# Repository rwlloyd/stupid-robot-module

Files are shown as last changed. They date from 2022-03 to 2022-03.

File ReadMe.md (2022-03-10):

# Stupid Robot Module

An Example of building firmware for a multi-motor, serial controlled module for robotics applications.

module consists of a hoverboard wheel driven by a JY-01 500W brushless motor driver with hall sensor feedback. Drive Direction is controlled by a brushed DC motor and incremental encoder configured as a servo. Homing is achieved using a digital hall sensor and a magnet attached to one of the servo gears. The servo motor is driven by a L298D H-bridge. IO signals to the motors and sensors are provided by an Arduino Nano. Control signals are sent to the Arduino via Serial connection from a companion computer.

## Repository Structure

- ./Firmware/stupid-robot-module
    - main folder for arduino firmware. configuration for the functions already implemented can be done via config.h. 
    - modules
        - bigServo - l298d motor driver and incremental encoder. runs a position controll pid loop. homing doesn't work well, but after that it's fine.
        - comms - serial communication using a string of bytes. in this instance;
        
                [error, desiredAngle, wheelSetpoint, wheelDirection, wheelMode]

        - safety - a facility to check stops and do error checking
        - ucontrol - facility to setup the microcontroller timer. Currently stops the PWM signals being in the audible range.
        - wheel - controls the wheel via a JY-01 brushless motor driver with feedback. Position control and velocity control modes are implemented.

- ./Hardware
    - STLs and other drawings of the prototype. Have a look, but you are encouraged to roll your own.

- ./Kicad
    - The beginnings of a custom controller PCB

- ./Processing
    - Rudimentary user interface that connects from the host computer and controls the module via serial communication

If you want more information, raise an issue on the github repository :)

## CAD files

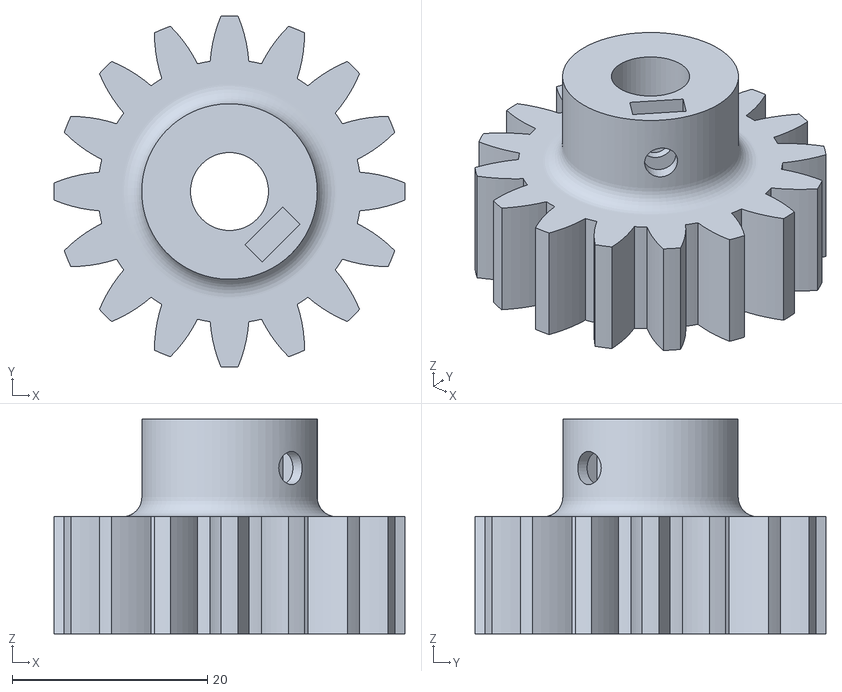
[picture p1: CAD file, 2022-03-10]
Hardware/Spur Gear1-Prototype.stl
36.0 x 36.0 x 22.0

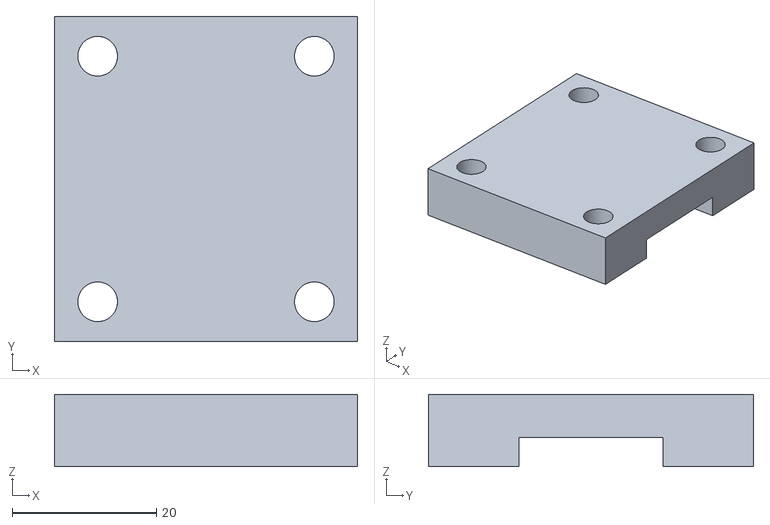
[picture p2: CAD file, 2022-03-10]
Hardware/WheelSprocketClamp.stl
42.0 x 45.0 x 10.0

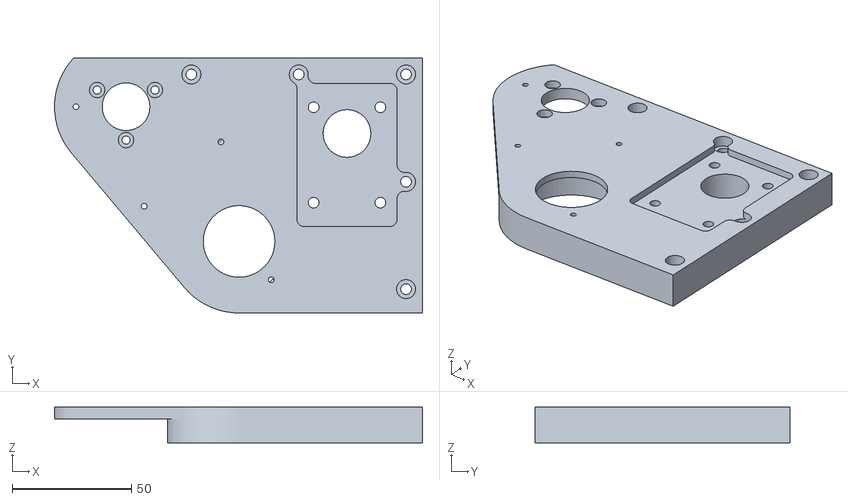
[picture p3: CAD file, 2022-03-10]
Hardware/SteeringMotorBracket-print.stl
154.3 x 106.9 x 15.0

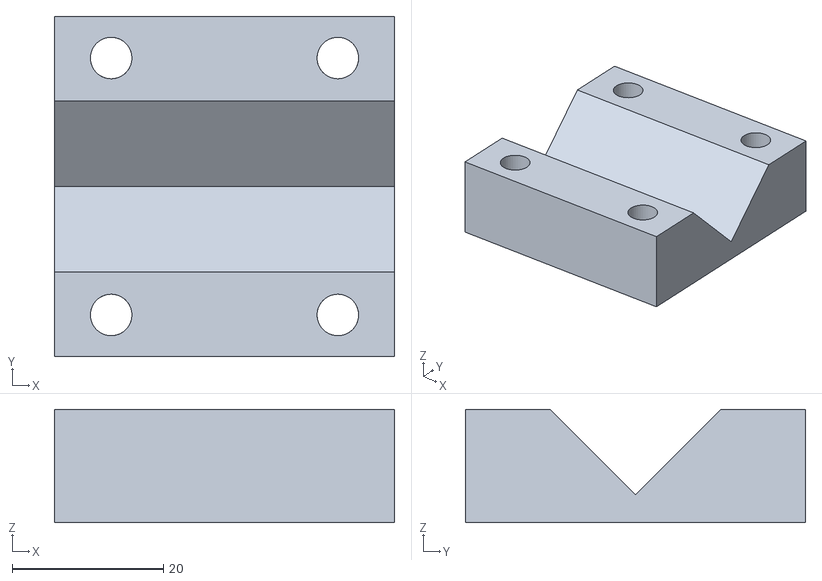
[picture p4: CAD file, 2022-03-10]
Hardware/DriveWheelVBlock.stl
45.0 x 45.0 x 15.0

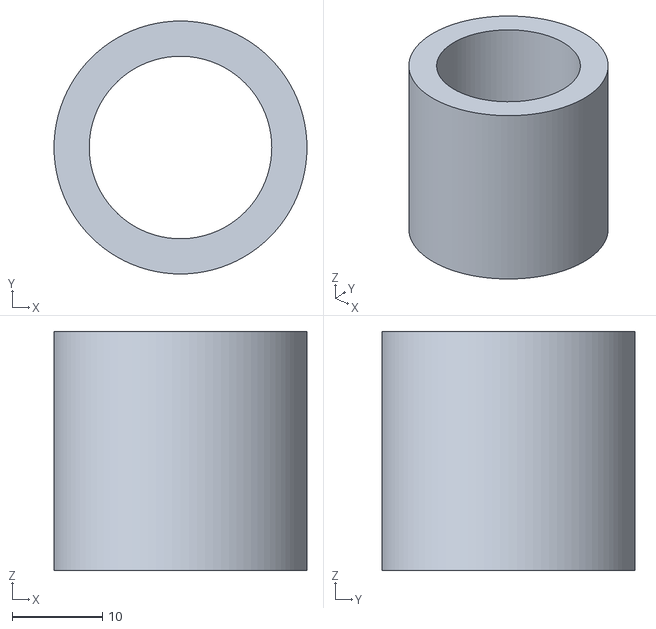
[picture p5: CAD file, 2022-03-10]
Hardware/ShaftCollar-id20.1x26.5mm.stl
28.0 x 28.0 x 26.5

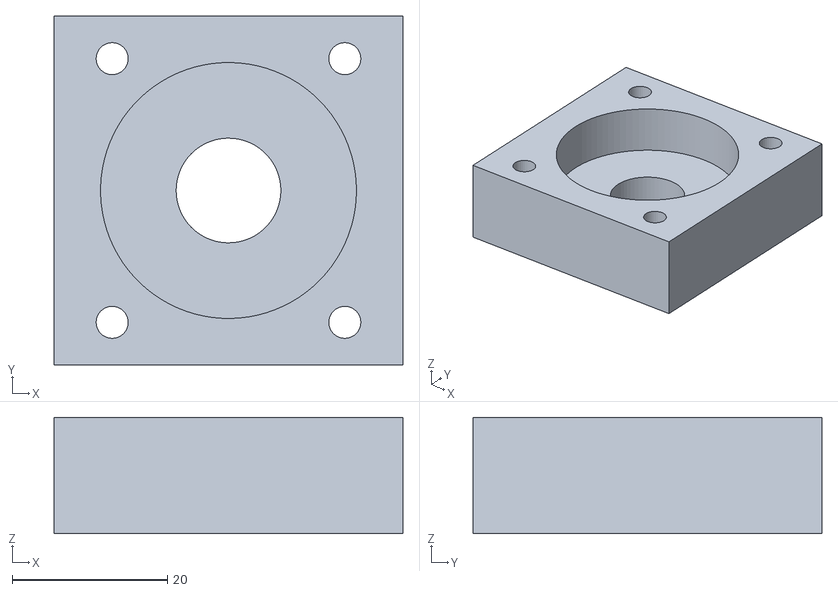
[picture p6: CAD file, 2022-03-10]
Hardware/ExtrusionCoupler.stl
45.0 x 45.0 x 15.0

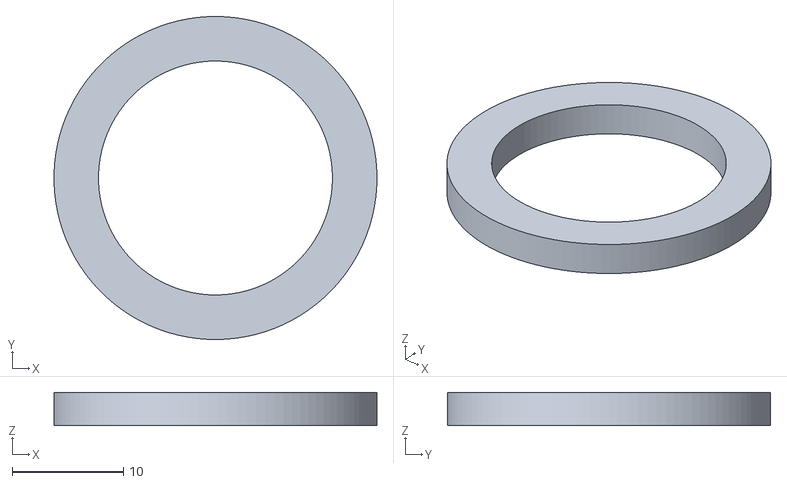
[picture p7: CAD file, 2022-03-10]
Hardware/Servo-Prototype-3mmShaftSpacer.stl
29.0 x 29.0 x 3.00

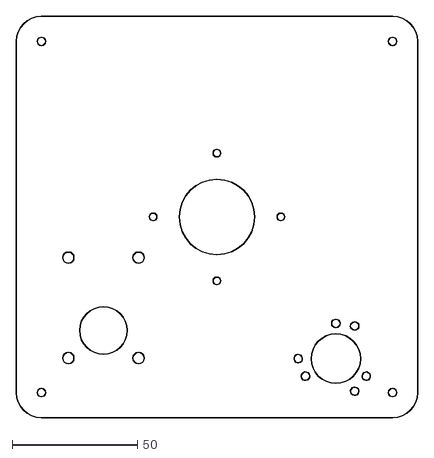
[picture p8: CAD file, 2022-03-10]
Hardware/Servo-Prototype.dxf
160.0 x 160.0

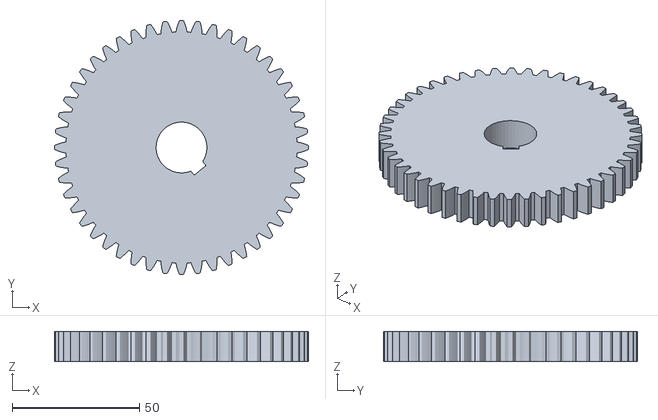
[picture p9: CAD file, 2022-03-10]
Hardware/Spur Gear2-Prototype.stl
100.0 x 100.0 x 12.0

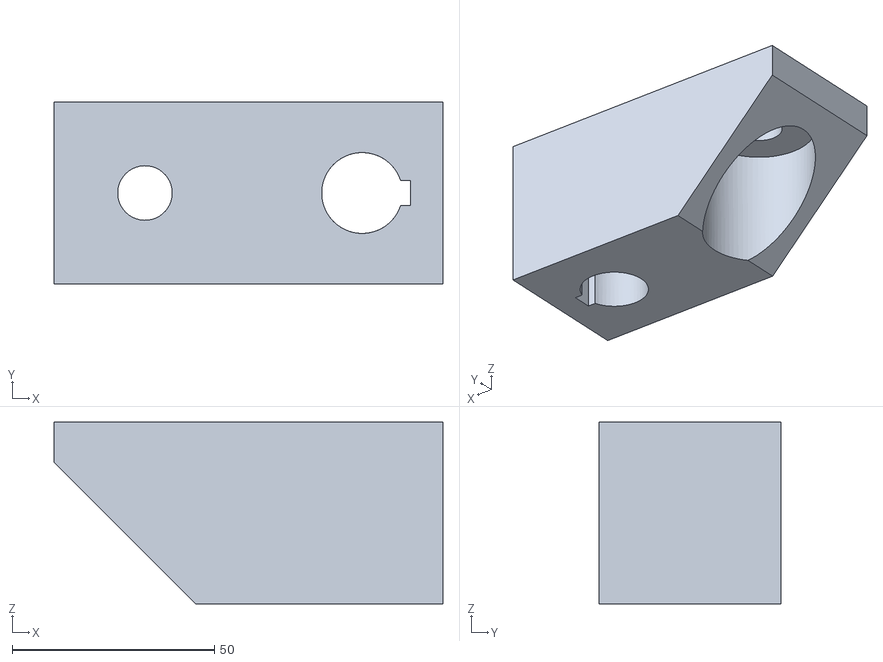
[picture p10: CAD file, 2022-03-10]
Hardware/WheelLegTransitionBlock.stl
96.2 x 45.0 x 45.0

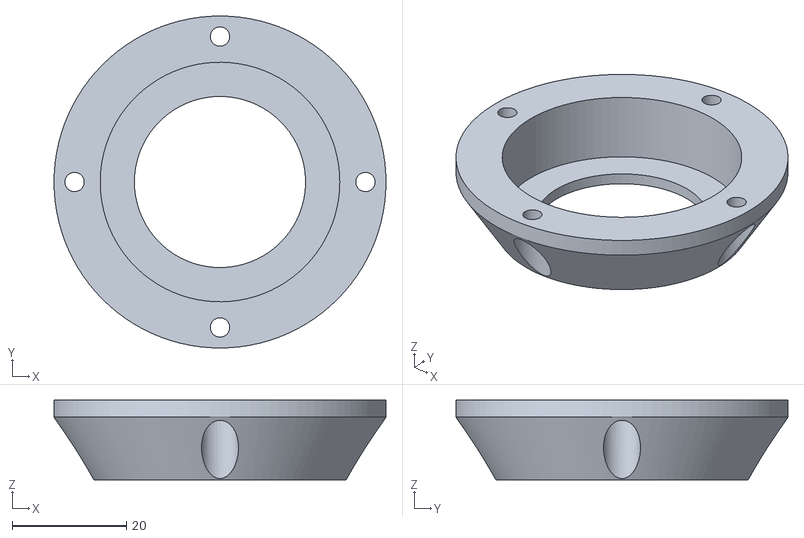
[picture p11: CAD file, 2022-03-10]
Hardware/BigBearingCover.stl
58.2 x 58.2 x 14.0

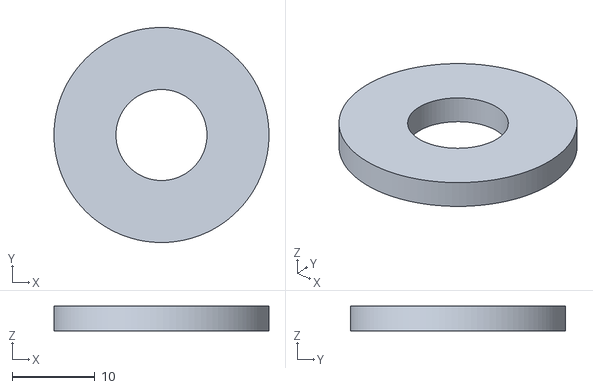
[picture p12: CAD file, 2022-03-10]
Hardware/ShaftCaptureWasher-ID11mm-OD26mm-x3mm.stl
26.0 x 26.0 x 3.00

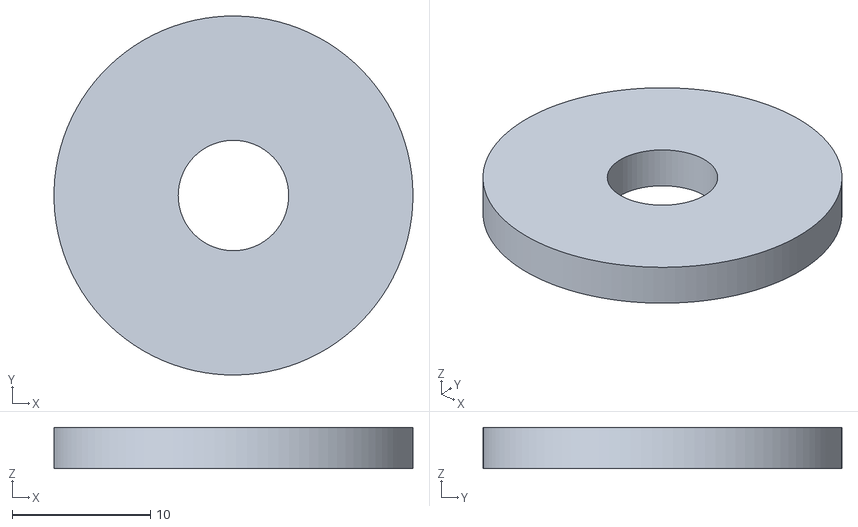
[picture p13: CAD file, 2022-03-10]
Hardware/ShaftCaptureWasher-ID8mm-OD24mm-x3mm.stl
26.0 x 26.0 x 3.00

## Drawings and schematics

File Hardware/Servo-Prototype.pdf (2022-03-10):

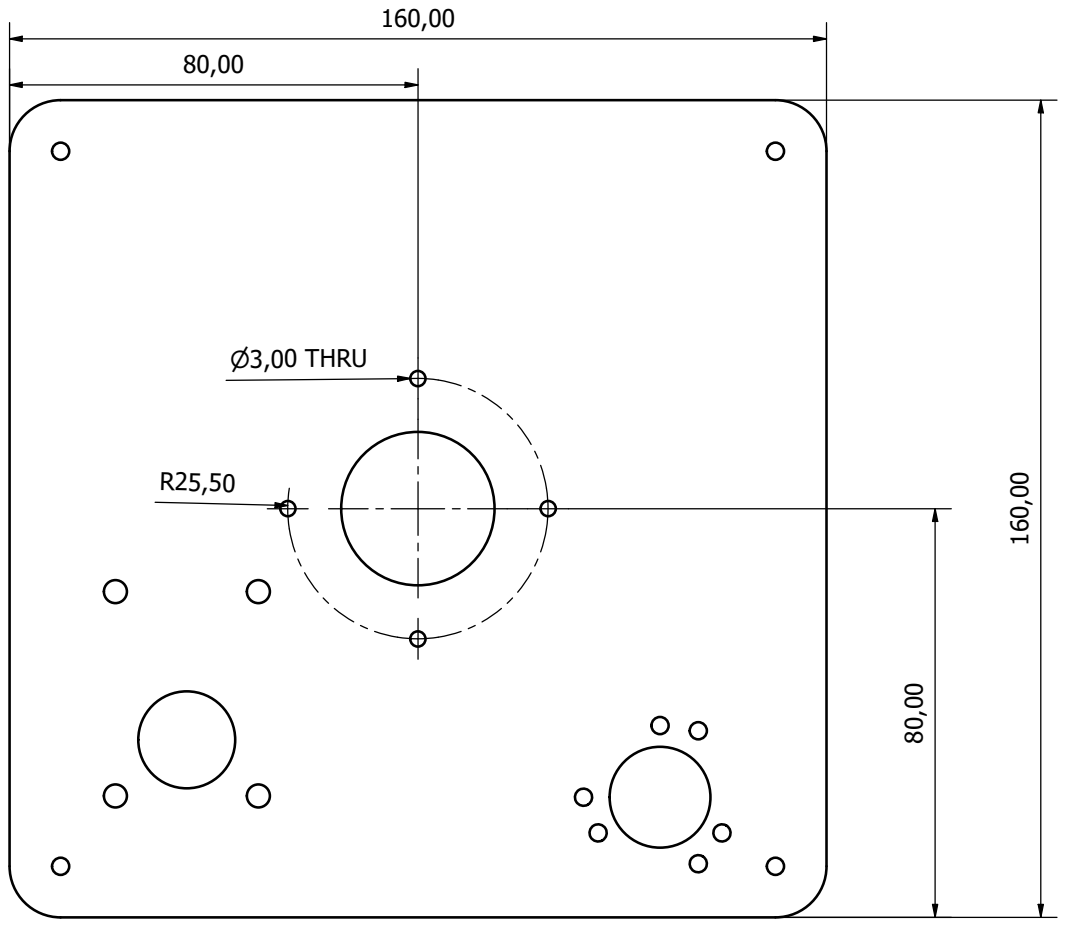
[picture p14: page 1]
Designed by; Checked by; Approved by; Date

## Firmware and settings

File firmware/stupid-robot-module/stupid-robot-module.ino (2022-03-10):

/*
   This file structure is an attampt to modularize what are becoming uncomfortably lengthy piles of code.
   https://forum.arduino.cc/t/how-to-properly-include-functions-written-on-other-sketch-tabs/565672/4#msg4005111

*/
#include "safety.h"
#include "comms.h"
#include "bigServo.h"
#include "wheel.h"

void setup() {
  startSafety();
  startComms();
  startServo();
  startWheel();
  doServoHoming();
}

void loop() {
  checkComms();
  if (!error) {
    doWheelControl(); // Modes: 0: basic, 1:velocity, 2:position
    doServoControl();
  }
}

/*

   Simple Processing sketch to control module

  import processing.serial.*;
  Serial myPort;

  byte[] inBuffer = new byte[3];
  int[] myString;

  boolean error = false;


  boolean contServo = false;
  boolean contWheel = false;

  int servoAngle = 0; // 0-255
  int wheelSpeed  = 0;

  void setup() {
  frameRate(30);
  size(500, 500);
  background(51);
  printArray(Serial.list());

  myPort = new Serial(this, Serial.list()[1], 115200);
  myPort.clear();
  sendCommand(false, 0, 0);
  }

  void draw() {
  background(51);
  while (myPort.available() > 0) {
    inBuffer = myPort.readBytes();
    myPort.readBytes(inBuffer);
    if (inBuffer != null) {
      myString = int(inBuffer);
      println(myString);
    }
  }
  stroke(255);
  // Draw neutral Line
  line(0, height/2, width, height/2);
  // Display enabled status
  if (error) {
    text("Motors Enabled", 20, height - 20);
  } else {
    text("Motors Disabled", 20, height - 20);
  }
  //if (contTool) {
  //  text("Tool Control Enabled", 20, height - 40);
  //} else {
  //  text("Tool Control Disabled", 20, height - 40);
  //}
  //if (contSteer) {
  //  text("Steering Control Enabled", 20, height - 60);
  //} else {
  //  text("Steering Control Disabled", 20, height - 60);
  //}
  //// Display tool height
  //text("Tool Height " + floor(map(tool_height, 0, 255, 0, 100)) + "%", 200, height - 20);
  //// Display steering Status

  //text("Steer " + steer, 300, height - 20);

  //if (!contTool) {
  //  tool_height = last_tool_height;
  //}
  //if(!contSteer){
  //  steer = 127;
  //}


  sendCommand(error, servoAngle, wheelSpeed);
  }

  void mousePressed() {
  wheelSpeed = abs(int(map(mouseY, 0, height, 0, 255)));
  servoAngle = abs(int(map(mouseX, 0, width, 0, 255)));
  }

  void sendCommand(boolean error_in, int servo_angle_in, int wheel_speed_in) {
  myPort.write(byte(error_in));
  myPort.write(byte(servo_angle_in));
  myPort.write(byte(wheel_speed_in));
  }

  void keyPressed() {
  // 'e' = toggle enable
  if (key == 'e' || key == 'E') {
    error =! error;
  }
  }
*/

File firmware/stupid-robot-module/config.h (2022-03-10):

#ifndef CONFIG_H
#define CONFIG_H
#include <Arduino.h>

#define errorPin 12
// Communication 
#define MESSAGELENGTH 5
#define BAUDRATE 115200

// Big Servo
#define enA 11          //Enable pin to motor driver
#define in1 9           //L298N in 1
#define in2 10          //L298N in 2
#define hallS 4         // Inverted Hall Sensor Input
#define potPin A0       // Analog input for adjustment
#define buttonPin 11    // Button Pin 

#define ENCODER_NUM_LINES 1000
#define ENCODER_PULLEY_RATIO 2.5
#define encoder0PinA 2  // Encoder 0 pin A
#define encoder0PinB 3  // Encoder 0 pin B

#define SERVO_HOME_OFFSET 0;

// Servo PID Gains
#define SERVO_P 10
#define SERVO_I 0.1
#define SERVO_D 0



// Wheel

#define WHEEL_DIA_MM 165

#define WHEEL_EN_PIN 8
#define WHEEL_SIGNAL_PIN 7
#define WHEEL_DIRECTION_PIN 6
#define WHEEL_SPEED_PIN 5

// Motor Driver deadzon (+/-)
#define WHEEL_SPEED_THRESHOLD 15
// Wheel Velocity PID Gains
#define WHEEL_VEL_P 3
#define WHEEL_VEL_I 0.1
#define WHEEL_VEL_D 0

// Wheel Position PID Gains
#define WHEEL_POS_P 1
#define WHEEL_POS_I 0
#define WHEEL_POS_D 0

// Wheel Hall Sensor Pins
#define WHEEL_HALL_FB_A A1
#define WHEEL_HALL_FB_B A2
#define WHEEL_HALL_FB_C A3

#define WHEEL_NUM_POLES 45

#endif

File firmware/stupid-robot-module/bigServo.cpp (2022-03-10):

#include "config.h"
#include "bigServo.h"
#include "Arduino.h"
#include "PinChangeInterrupt.h"
#include "ucontrol.h"

#include "PID_v1.h"
#include "avr/interrupt.h"

bool debugServo = false;
int desiredAngle = 0;

int rotDirection = 0;
int pressed = false;

double encoder0Pos = 0;
unsigned int tmp_Pos = 1;

// Variable for pulses per rotation of incremental encoder
int steps = ENCODER_NUM_LINES;
// Variable for encoder pulley:shaft pulley ratio. eg. 40:16 = 2.5
float ratio = ENCODER_PULLEY_RATIO;
// calculate encoder steps for one shaft rotation
float shaftSteps = steps * ratio;
float resolution = 360 / shaftSteps;

int currentPoint = 0;
boolean A_set;
boolean B_set;

bool homed = false;
int homeStatus = 0;
bool magnetFound = false;
bool magnetSize = 0;
bool detected = false;
int magnetMax = 0;
int magnetMin = 0;

//PID STUFF

//Define Variables we'll be connecting to
double serSetpoint, serInput, serOutput, serOutputA;

//Specify the links and initial tuning parameters
double sKp = SERVO_P, sKi = SERVO_I, sKd = SERVO_D;
PID motorPID(&serInput, &serOutput, &serSetpoint, sKp, sKi, sKd, DIRECT);

unsigned long currentMillis;
long previousMillis = 0;    // set up timers
long interval = 40;        // time constant for timers

// Interrupt on A changing state
void doEncoderA() {
  // Low to High transition?
  if (digitalRead(encoder0PinA) == HIGH) {
    A_set = true;
    if (!B_set) {
      encoder0Pos++;
    }
  }
  // High-to-low transition?
  if (digitalRead(encoder0PinA) == LOW) {
    A_set = false;
  }
}


// Interrupt on B changing state
void doEncoderB() {
  // Low-to-high transition?
  if (digitalRead(encoder0PinB) == HIGH) {
    B_set = true;
    if (!A_set) {
      encoder0Pos--;
    }
  }
  // High-to-low transition?
  if (digitalRead(encoder0PinB) == LOW) {
    B_set = false;
  }
}

void doHall() {
  // Read the hall sensor. its pin is pulled up, so true is low.
  // detection of magnet
  if (digitalRead(hallS) == LOW) {
    detected = true;
  }
  if (digitalRead(hallS) == HIGH) {
    detected = false;
  }
}

void startServo() {

  setServoPWM();

  pinMode(enA, OUTPUT);
  pinMode(in1, OUTPUT);
  pinMode(in2, OUTPUT);
  pinMode(hallS, INPUT_PULLUP);
  pinMode(potPin, INPUT);
  pinMode(buttonPin, INPUT_PULLUP);
  // Set initial rotation direction
  digitalWrite(in1, LOW);
  digitalWrite(in2, HIGH);

  pinMode(encoder0PinA, INPUT);
  pinMode(encoder0PinB, INPUT);

  // encoder pin on interrupt 0 (pin 2)
  attachInterrupt(0, doEncoderA, CHANGE);
  // encoder pin on interrupt 1 (pin 3)
  attachInterrupt(1, doEncoderB, CHANGE);

  attachPCINT(digitalPinToPCINT(hallS), doHall, CHANGE);

  int deadZone = 10;

  //turn the PID on
  motorPID.SetMode(AUTOMATIC);
  motorPID.SetOutputLimits(-255, 255);
  motorPID.SetSampleTime(20);

  Serial.begin(BAUDRATE);
  if (debugServo) {
    Serial.print("Calculated Steps per rotation: "); Serial.println(shaftSteps);
    Serial.print("Calculated angular resolution: "); Serial.print(resolution); Serial.println(" degs per encoder tick");
  }
}

void goClock(int s) {
  analogWrite(in1, 0);
  analogWrite(in2, s);
}

void goAntiClock(int s) {
  analogWrite(in1, s);
  analogWrite(in2, 0);
}

bool seekedClock = false;

void doServoHoming() {
  if (!homed && !detected) {
    if (encoder0Pos > (shaftSteps * 0.2)) {
      seekedClock = true;
    }
    if (!seekedClock) {
      goClock(127);
    } else if (seekedClock) {
      goAntiClock(127);
    }
    homeStatus = 1;
  }
  if (homeStatus == 1 && detected) {
    encoder0Pos = SERVO_HOME_OFFSET;
    homed = true;
  }
}

float stepsToAngle(int steps) {
  return float(steps * resolution);
}

float angleToSteps(float angle) {
  return (angle / resolution);
}

float currentAngle() {
  return stepsToAngle(encoder0Pos);
}

void gotoPosition(int p) {
  serSetpoint = p;
}

void gotoAngle(int a) {
  serSetpoint = angleToSteps(a);
}

void doServoControl() {
  if (!homed) {
    doServoHoming();
  }
  currentMillis = millis();
  if (currentMillis - previousMillis >= interval) {  //start timed event
    previousMillis = currentMillis;

    motorPID.Compute();

//    Setpoint = map(analogRead(A0), 0, 1024, 0, 255); // only here for testing
//    Input = map(encoder0Pos, 0, shaftSteps, 0, 255);

    serSetpoint = angleToSteps(map(desiredAngle, 0, 255, 0, 360));

    serInput = encoder0Pos;

    if (serOutput > 0) {
      analogWrite(in1, serOutput);
      analogWrite(in2, 0);
    }
    else if (serOutput < 0) {
      serOutputA = abs(serOutput);
      analogWrite(in1, 0);
      analogWrite(in2, serOutputA);
    }

    // Run the motor by enabling the driver with a PWM signal
    //    analogWrite(enA, Output); // Send PWM signal to L298N Enable pin
    analogWrite(enA, HIGH);
  }
}

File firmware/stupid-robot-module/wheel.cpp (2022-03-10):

#include "safety.h"
#include "config.h"
#include "wheel.h"
#include "arduino.h"
#include "PinChangeInterrupt.h"
#include "PID_v1.h"

// Generally useful information about brushless motors
// https://www.nxp.com/docs/en/application-note/AN10661.pdf

int wheel_EN_pin = WHEEL_EN_PIN;  //EL
int wheel_Signal_hall_pin = WHEEL_SIGNAL_PIN;   // Signal - Hall sensor <-- This can be used as a speedo/odom signal
int wheel_ZF_Direction_pin = WHEEL_DIRECTION_PIN;  // ZF
int wheel_VR_speed_pin = WHEEL_SPEED_PIN;    //VR

// inputs
int wheelSetpoint = 0;
int wheelDirection = false;
int wheelMode = 0;

bool debug = false;

// globals
int wheelSpeed = 0;
float wheelRealSpeed = 0; // speed in rpm
int wheelSignalPos = 0;
// Variables to help filtering the velocity calculations
float velocityFiltered = 0;
float velocityFilteredPrev = 0;

// 0-255 signal used when in position control
float power = 0;

long prevT = 0;
int posPrev = 0;
// Use the "volatile" directive for variables
// used in an interrupt
volatile int pos_i = 0;
volatile float velocity_i = 0;
volatile long prevT_i = 0;
// Variable to keep track of the BLDC Phases and direction
volatile boolean encAVal = 0;
volatile bool encBVal = 0;
volatile bool encCVal = 0;
volatile bool encDir = 0;

//PID STUFF

//Define Variables we'll be connecting to
double velSetpoint, velInput, velOutput, velOutputA;

//Specify the links and initial tuning parameters
double vKp = WHEEL_VEL_P, vKi = WHEEL_VEL_I, vKd = WHEEL_VEL_D;
PID velPID(&velInput, &velOutput, &velSetpoint, vKp, vKi, vKd, DIRECT);

//Define Variables we'll be connecting to
double posSetpoint, posInput, posOutput, posOutputA;

//Specify the links and initial tuning parameters
double pKp = WHEEL_POS_P, pKi = WHEEL_POS_I, pKd = WHEEL_POS_D;
PID posPID(&posInput, &posOutput, &posSetpoint, pKp, pKi, pKd, DIRECT);

unsigned long currentWheelMillis; // for pid
long previousWheelMillis = 0;    // set up timers for pid
long wheelInterval = 35;        // time constant for pid timers

long previousSpeedMillis = 0;
unsigned long currentSpeedMillis;
long speedInterval;
int current_wheel_speed = WHEEL_NUM_POLES / speedInterval;

void startWheel() {
  Serial.begin(115200);
  pinMode(potPin, INPUT);
  pinMode(wheel_EN_pin , OUTPUT);           //stop/start - EL
  pinMode(wheel_Signal_hall_pin , INPUT);   //plus       - Signal
  pinMode(wheel_ZF_Direction_pin , OUTPUT); //direction  - ZF

  //Hall sensor detection - Count stps
  //attachInterrupt(digitalPinToInterrupt(wheel_Signal_hall_pin), odom, CHANGE);
  //https://github.com/NicoHood/PinChangeInterrupt/blob/master/examples/PinChangeInterrupt_Led/PinChangeInterrupt_Led.ino
  attachPCINT(digitalPinToPCINT(wheel_Signal_hall_pin), odom, CHANGE);

  pinMode(WHEEL_HALL_FB_A, INPUT);
  pinMode(WHEEL_HALL_FB_B, INPUT);
  pinMode(WHEEL_HALL_FB_C, INPUT);
  attachPCINT(digitalPinToPCINT(WHEEL_HALL_FB_A), doA, CHANGE);
  attachPCINT(digitalPinToPCINT(WHEEL_HALL_FB_B), doB, CHANGE);
  attachPCINT(digitalPinToPCINT(WHEEL_HALL_FB_C), doC, CHANGE);

  //turn the PID on
  velPID.SetMode(AUTOMATIC);
  velPID.SetOutputLimits(-255, 255);
  velPID.SetSampleTime(20);

  //turn the PID on
  posPID.SetMode(AUTOMATIC);
  posPID.SetOutputLimits(-255, 255);
  posPID.SetSampleTime(10);

}

void doWheelControl() {
  velPID.Compute();
  posPID.Compute();
  //displayMotorSignals();

  // 30ms loop
  currentWheelMillis = millis();
  if (currentWheelMillis - previousWheelMillis >= wheelInterval) {  //start timed event
    previousWheelMillis = currentWheelMillis;

    calculateRealSpeed();


    if (wheelMode == 0) {
      doBasicControl();
    } else if (wheelMode == 1) {
      doVelocityControl();
    } else if (wheelMode == 2) {
      doPositionControl();
    }
  }
}

void doBasicControl() {
  //int BasicSetpoint = floor(map(analogRead(potPin), 0, 1024, -254, 254));
  int basicSetpoint = wheelSetpoint;
  if (!wheelDirection){
    basicSetpoint = -1* basicSetpoint;
  }
  if (basicSetpoint == 0) {
    wheelStop();
  }
  else if (basicSetpoint > 0) {
    wheelMove(abs(basicSetpoint), wheelDirection);
  }
  else if (basicSetpoint < 0) {
    wheelMove(abs(basicSetpoint), wheelDirection);
  }
  if (debug) {
    Serial.print(basicSetpoint);
    Serial.print(",");
    Serial.println(wheelSignalPos);
  }
}

void doVelocityControl() {
  //https://github.com/curiores/ArduinoTutorials/blob/main/SpeedControl/SpeedControl_NoAtomic/SpeedControl_NoAtomic.ino

  if (debug) {
    displayWheelSpeeds();
  }

  //velSetpoint = map(analogRead(A0), 0, 1024, -25, 25);
  velSetpoint = wheelSetpoint / 10;
  if (!wheelDirection){
    velSetpoint = -1* velSetpoint;
  }
  velInput = velocityFiltered;
  if (velOutput > 0) {
    wheelMove(constrain(abs(velOutput), 0, 254), wheelDirection);
  }
  else if (velOutput < 0) {
    wheelMove(constrain(abs(velOutput), 0, 254), wheelDirection);
  }
}

void doPositionControl() {
  // https://github.com/curiores/ArduinoTutorials/blob/main/encoderControl/part4_NoAtomic/part4_NoAtomic.ino

  if (debug) {
    displayWheelPositions();
  }

  //posSetpoint = map(analogRead(A0), 0, 1024, -300, 300);
  posSetpoint = wheelSetpoint;
  if (!wheelDirection){
    posSetpoint = -1* posSetpoint;
  }
  posInput = wheelSignalPos;

  power = fabs(posOutput);
  if (power > 255) {
    power = 255;
  }
  if (posOutput > 0) {
    wheelMove(power, true);
  }
  else if (posOutput < 0) {
    wheelMove(power, false);
  }
}

void wheelStop() {
  digitalWrite(wheel_EN_pin , LOW);
}

void wheelMove(int s_new, bool dir_new) {
  int s = floor(abs(map(s_new, 0, 255, WHEEL_SPEED_THRESHOLD, 255)));
  analogWrite(wheel_VR_speed_pin, s_new);
  //digitalWrite(wheel_EN_pin , LOW);
  digitalWrite(wheel_ZF_Direction_pin , dir_new);
  digitalWrite(wheel_EN_pin, HIGH);
}

void displayMotorSignals() {
  Serial.print(encDir + 2);
  Serial.print(",");
  Serial.print(digitalRead(WHEEL_HALL_FB_A));
  Serial.print(",");
  Serial.print(digitalRead(WHEEL_HALL_FB_B) - 2);
  Serial.print(",");
  Serial.println(digitalRead(WHEEL_HALL_FB_C) - 4);
}

void calculateRealSpeed() {
  //https://github.com/curiores/ArduinoTutorials/blob/main/SpeedControl/SpeedControl_NoAtomic/SpeedControl_NoAtomic.ino
  // read the position and velocity
  int pos = 0;
  float velocity = 0;
  noInterrupts(); // disable interrupts temporarily while reading
  pos = wheelSignalPos;
  velocity = velocity_i;
  interrupts(); // turn interrupts back on

  // Compute velocity with by counting Signal ticks between loops
  long currT = micros();
  float deltaT = ((float) (currT - prevT)) / 1.0e6;
  velocity = (pos - posPrev) / deltaT;
  posPrev = pos;
  prevT = currT;

  // Convert count/s to RPM
  wheelRealSpeed = velocity / 600.0 * 60.0;
  // Low-pass filter (25 Hz cutoff)
  // Calculates the filtered angular velocity of wheel in rpm
  velocityFiltered = 0.854 * velocityFiltered + 0.0728 * wheelRealSpeed + 0.0728 * velocityFilteredPrev;
  velocityFilteredPrev = wheelRealSpeed;
}
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
